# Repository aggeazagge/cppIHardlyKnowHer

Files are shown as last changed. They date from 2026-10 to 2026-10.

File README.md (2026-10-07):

# Autonomonomous car by C++, I hardly know her

A school project building autonomous vehicles that drive themselves along a
walled track about 1 m wide. The firmware is written in MicroPython for an
ESP32-family board. Each vehicle uses three time-of-flight distance sensors to
stay centered between the walls, a Pololu Motoron motor controller, and a start
module that tells it when to go.

### Code

| Folder | Vehicle | Description |
|---|---|---|
| [snok_1.2](snok_1.2/README.md) | RC car | Ackermann steering with a servo and one drive motor. Detects when it is stuck and reverses out |
| [huggorm_1.0](huggorm_1.0/README.md) | Tracked chassis | Excavator with two tracks, steers by the speed difference between them |

Each folder is a complete firmware. To run one, copy its `config.py`, `main.py`
and `lib/` to the board, for example with Thonny. All tunable values are in `config.py`.

### Components

- VL53L4CX ToF lidar sensor – left and right side sensors
- VL53L0X ToF lidar sensor – front (middle) sensor
- Pololu Motoron M2T550 dual I2C motor controller
- DC-DC step-down converter (1.23–30 V, 1.5 A)
- Slide switch (on-on)
- GT Power B3 battery charger

### PCB-schematics

[Kicad/Bil v 1,0](Kicad/Bil%20v%201,0) contains the KiCad project for the
car's circuit board: the schematic, the PCB layout, and the custom symbol
libraries (`Auto_car_library`, `motron_i2c_3motor`).

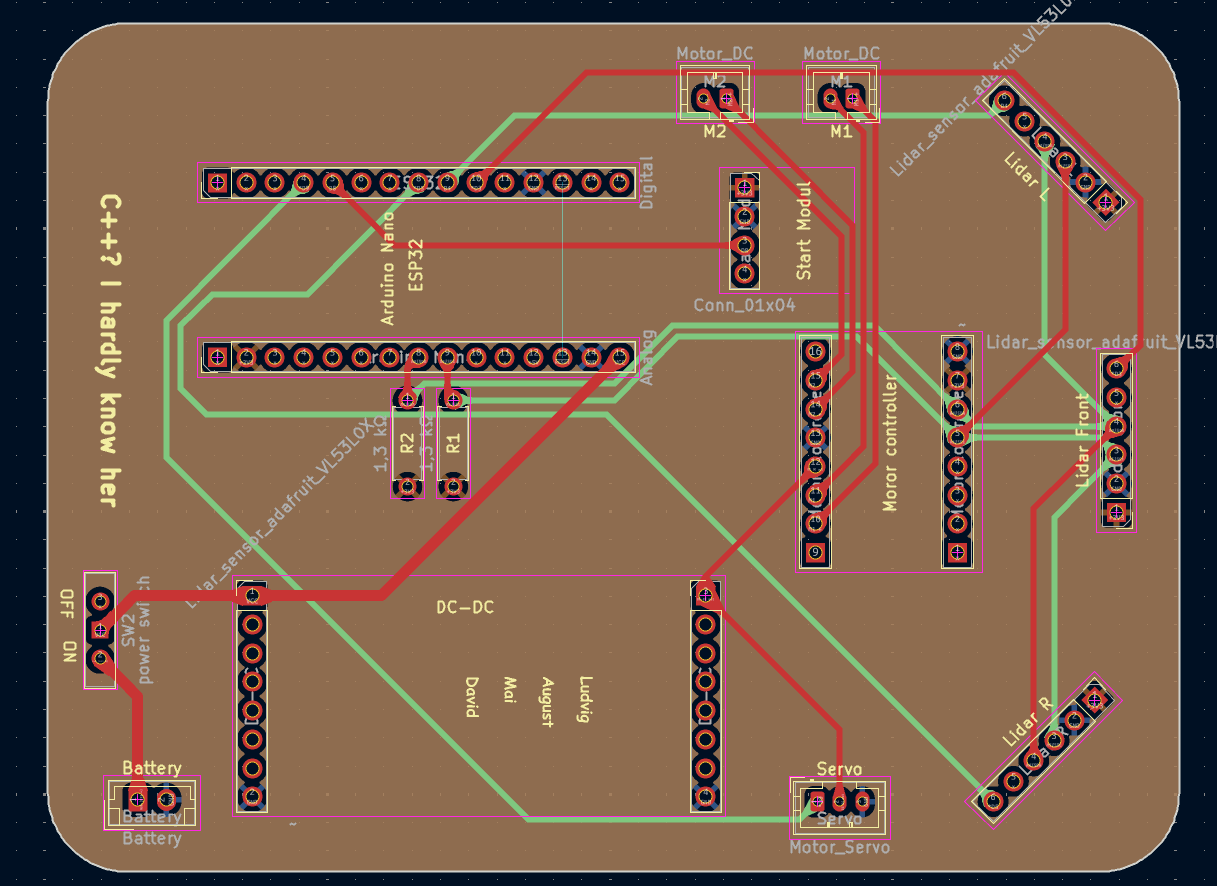
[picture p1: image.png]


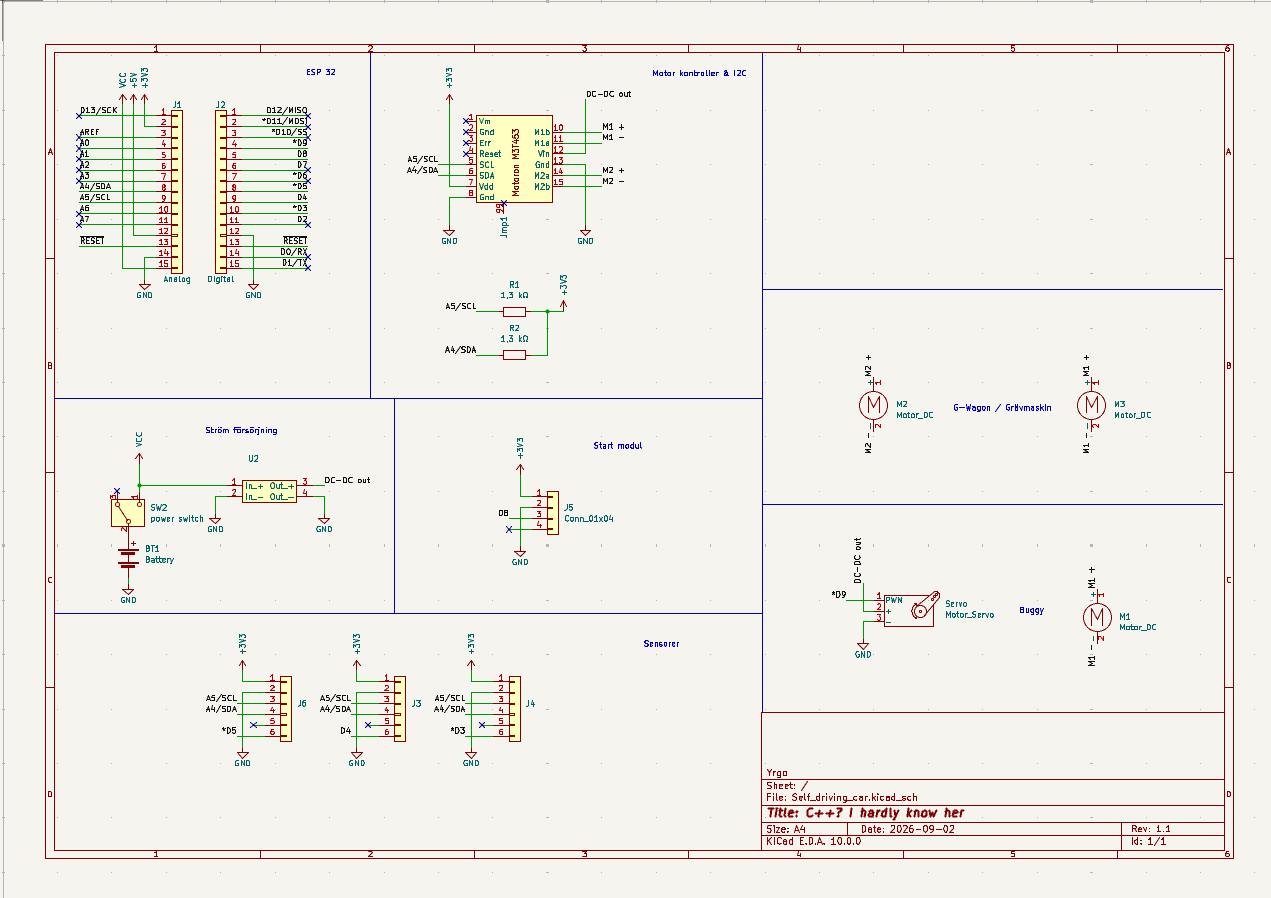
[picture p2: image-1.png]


### License

See [LICENSE](LICENSE).

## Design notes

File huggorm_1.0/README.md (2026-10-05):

# Huggorm 1.0 – autonomous tracked chassis firmware

MicroPython firmware for a tracked, skid-steer chassis with two independent
tracks and no steering servo. It drives itself down a walled track about 1 m
wide, using three time-of-flight sensors to stay centered: VL53L4CX sensors on
the left and right, angled outward, and a VL53L0X in the middle. Both tracks run
at `CRUISE_SPEED`, and the chassis steers by slowing the inside track. There is
no reverse.

## Hardware / wiring

ESP32-family MicroPython board. The pin numbers come from `config.py` and
`lib/lidar_sensor.py`.

| Signal | Pin | Notes |
|---|---|---|
| I2C SDA / SCL | GPIO11 / GPIO12 | shared bus for the sensors and the Motoron, 400 kHz |
| Left ToF (VL53L4CX) XSHUT | GPIO8 | reassigned to `0x30` |
| Middle ToF (VL53L0X) XSHUT | GPIO6 | default `0x29` |
| Right ToF (VL53L4CX) XSHUT | GPIO7 | reassigned to `0x31` |
| Start module | GPIO17 | level and pull set in `config.py` |

The Motoron is at `0x10` and drives the left track on channel 1 and the right
track on channel 2.

All three sensors power up at address `0x29`. To fix that, `lidar_sensor.py`
holds them in reset with XSHUT and then releases them one at a time, giving each
its own address. This has to happen before the Motoron is set up, because
`main.py` reuses the same I2C bus.

## How it runs

`boot.py` is the stock stub. `main.py` sets up the Motoron and calls `run()`,
an infinite loop that only drives while the start pin is active. While the pin
is inactive, it brakes both tracks.

To deploy, copy `boot.py`, `config.py`, `main.py` and `lib/` to the board and
power-cycle it.

## Control loop

Every ~10 ms (`LOOP_DELAY_MS`): read sensors → `compute(dl, dr)` → set track
speeds.

- **Steering fraction:** `dr - dl` is clamped to `±STEER_SPAN_MM` and turned
  into a fraction from -1 (full left) to +1 (full right).
- **Differential speed:** only the inside track slows down:
  `left = CRUISE_SPEED * (1 - TURN_SLOWDOWN * max(0, -frac))`, and the same for
  `right` with `max(0, frac)`. The outside track always runs at full speed.
- The middle sensor is read and logged but not used for control.
- There is no reverse. A pivot turn would be possible on this chassis and could
  be added if `TURN_SLOWDOWN` isn't enough for sharp corners.

## Sensors and safety

- Readings of `0` or `>= DIST_MAX` count as "open", invalid range statuses
  are ignored, and a rolling median (`SENSOR_AVG_SAMPLES`, keep it odd) removes
  spikes.
- The sensors run in continuous mode (about 33 ms timing budget), so reading
  them is quick. A read that times out keeps the last value. A sensor is
  restarted after `SENSOR_RESTART_AFTER_FAILS` failures and declared dead after
  `SENSOR_MAX_FAILS`, which brakes the chassis.
- The Motoron command timeout is left on, so the tracks stop within about
  1.5 s if the loop hangs.
- If the start signal drops or the loop throws, `stop_all()` brakes both
  tracks.

## Tuning

Every bench-tunable constant is in `config.py` with a comment.

## File map

| File | Role |
|---|---|
| `boot.py` | MicroPython boot hook (unmodified stub) |
| `config.py` | All pins and tunable constants |
| `main.py` | Hardware setup, `compute()` and the `run()` loop |
| `lib/lidar_sensor.py` | I2C bus, sensor bring-up and smoothed `las_avstand()` |
| `lib/motoron.py`, `lib/motoron_protocol.py` | Pololu Motoron driver (vendored) |
| `lib/vl53l0x.py`, `lib/vl53l4cx.py` | ToF sensor drivers (vendored) |

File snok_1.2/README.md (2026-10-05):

# Snok 1.2 – autonomous RC car firmware

MicroPython firmware for an Ackermann-steered RC car (one drive motor and a
steering servo) that drives itself down a walled track about 1 m wide. It uses
three time-of-flight sensors to stay centered: VL53L4CX sensors on the left and
right, angled outward, and a VL53L0X in the middle. New in 1.2: the car notices
when it is stuck against an obstacle and reverses out.

## Hardware / wiring

ESP32-family MicroPython board. The pin numbers come from `config.py` and
`lib/lidar_sensor.py`.

| Signal | Pin | Notes |
|---|---|---|
| I2C SDA / SCL | GPIO11 / GPIO12 | shared bus for the sensors and the Motoron, 400 kHz |
| Left ToF (VL53L4CX) XSHUT | GPIO7 | reassigned to `0x30` |
| Middle ToF (VL53L0X) XSHUT | GPIO6 | default `0x29` |
| Right ToF (VL53L4CX) XSHUT | GPIO8 | reassigned to `0x31` |
| Steering servo | GPIO18 | 50 Hz, 544–2400 µs |
| Start module | GPIO17 | level and pull set in `config.py` |

The Motoron motor controller is at I2C address `0x10` and drives the motor on
channel 1. `MOTOR_INVERT = True` because the motor wires are swapped.

All three sensors power up at address `0x29`. To fix that, `lidar_sensor.py`
holds them in reset with XSHUT and then releases them one at a time, giving each
its own address. This runs when the module is imported, before the Motoron is
set up.

## How it runs

`main.py` is the entry point and calls `run()` at the bottom. `run()` is an
infinite loop that only drives while the start pin is active. While the pin is
inactive, it brakes and centers the wheels with `stop_all()`.

To deploy, copy `config.py`, `main.py` and `lib/` to the board (for example with
mpremote or Thonny) and power-cycle it.

## Control loop

Each iteration (`LOOP_DELAY_MS`) does: read sensors → compute steering and
speed → apply → repeat.

- **Steering:** `dr - dl` is clamped to `±STEER_SPAN_MM` and turned into a
  fraction from -1 (full left) to +1 (full right), which is then mapped to a
  servo angle around `STEER_CENTER_DEG`. The side sensors keep the car centered
  between the walls. They are not used as obstacle sensors.
- **Corners:** when the middle sensor reads below `DIST_SLOW`, the steering
  fraction is multiplied by `CORNER_STEER_GAIN` so the car commits harder to the
  turn, and speed drops by `TURN_SLOWDOWN`.
- **Speed:** speed depends only on the middle sensor. The car drives at
  `CRUISE_SPEED` at `DIST_CLEAR` or more, ramps down toward `DIST_STOP`, and
  never goes below `TURN_CRAWL_SPEED`.
- **Stuck detection (new):** `check_stuck()` reports the car as stuck when an
  obstacle is less than 250 mm ahead and the distance has changed by less than
  15 mm for 2 s. `backWard()` then reverses at `BACK_SPEED` for 1 s with the
  wheels straight.
- **Hill blackout:** if all three sensors read `DIST_MAX` for
  `BLACKOUT_CONFIRM_FRAMES` frames in a row, the car is probably pitched up on a
  hill and looking over the walls. It then holds half of the last steering
  angle and drives at `HILL_BLIND_SPEED`.

## Sensors and safety

- Readings of `0` or `>= DIST_MAX` count as "open", invalid range statuses
  are ignored, and a rolling median (`SENSOR_AVG_SAMPLES`) removes spikes.
- The sensors run in continuous mode, so reading them is quick. A read that
  times out keeps the last value. A sensor is restarted after
  `SENSOR_RESTART_AFTER_FAILS` failures and declared dead after
  `SENSOR_MAX_FAILS`, which brakes the car.
- The Motoron command timeout is left on, so the motor stops within about
  1.5 s if the loop hangs.
- Any exception in `run()` calls `stop_all()` before re-raising it.

More detail on the sensor stack is in [huggorm_1.0/README.md](../huggorm_1.0/README.md).

## Tuning

Every bench-tunable constant is in `config.py` with a comment: speeds,
distance thresholds, steering angles and gains, and sensor timing. Calibrate
`STEER_CENTER_DEG`, `STEER_LEFT_DEG` and `STEER_RIGHT_DEG` on the bench.

## File map

| File | Role |
|---|---|
| `config.py` | All pins and tunable constants |
| `main.py` | Hardware setup, `compute()`, stuck detection and reverse, the `run()` loop |
| `lib/lidar_sensor.py` | I2C bus, sensor bring-up and smoothed `las_avstand()` |
| `lib/servo.py` | Steering servo driver |
| `lib/motoron.py`, `lib/motoron_protocol.py` | Pololu Motoron driver (vendored) |
| `lib/vl53l0x.py`, `lib/vl53l4cx.py` | ToF sensor drivers (vendored) |

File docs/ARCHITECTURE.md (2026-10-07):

# Snok 1.2 Architecture

How the autonomous car's code is wired: three distance sensors feed a control law that drives the steering servo and the Motoron motor controller. Blue is the normal driving path; orange marks the safety paths (stop, blackout, reverse).

To view the full page, open [architecture.html](architecture.html) in a browser.

## System block diagram

System block diagram: sensors and start module feed lidar_sensor.py and main.py, which drive the steering servo and the Motoron motor controller

All three sensors and the Motoron share one I²C bus, created in `lib/lidar_sensor.py` and reused by `main.py`. A sensor that misses 3 reads in a row gets its continuous mode restarted; after 10 it raises, and `run()` catches the error and calls `stop_all()`. The Motoron's own command timeout also stops the motor if the loop stalls.

## Main loop

Flowchart of run() in main.py

One pass of `run()` in `main.py`. Any exception, including a dead sensor or Ctrl-C, leaves the loop through `stop_all()`. The blackout branch exists because the car pitches nose-up on a hill and all three beams can look over the walls.

| Setting (`Config.py`) | Value | Effect |
|---|---|---|
| `DIST_CLEAR` | 1000 mm | middle sensor at or above this → full cruise |
| `DIST_SLOW` | 750 mm | below this → slow down, steering ×3.5 |
| `DIST_STOP` | 300 mm | at or below this → crawl speed |
| `CRUISE_SPEED` | 250 | normal forward speed (Motoron units, max 800) |
| `STEER_LEFT/CENTER/RIGHT_DEG` | 60° / 90° / 120° | steering servo angles |
| `STEER_SPAN_MM` | 500 mm | `dr − dl` difference that gives full steering lock |

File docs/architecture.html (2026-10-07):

snok1.2 · MicroPython

# Snok 1.2 Architecture

How the autonomous car's code is wired: three distance sensors feed a control law that drives the steering servo and the Motoron motor controller. Blue is the normal driving path; orange marks the safety paths (stop, blackout, reverse).

## System block diagram

All three sensors and the Motoron share one I²C bus, created in lidar_sensor.py and reused by main.py. A sensor that misses 3 reads in a row gets its continuous mode restarted; after 10 it raises, and run() catches the error and calls stop_all(). The Motoron's own command timeout also stops the motor if the loop stalls.

## Main loop

One pass of run() in main.py. Any exception, including a dead sensor or Ctrl-C, leaves the loop through stop_all(). The blackout branch exists because the car pitches nose-up on a hill and all three beams can look over the walls.

DIST_CLEAR 1000 mm → cruise DIST_SLOW 750 mm → slow, steer ×3.5 DIST_STOP 300 mm → crawl CRUISE_SPEED 250 STEER 60° · 90° · 120° STEER_SPAN 500 mm = full lock

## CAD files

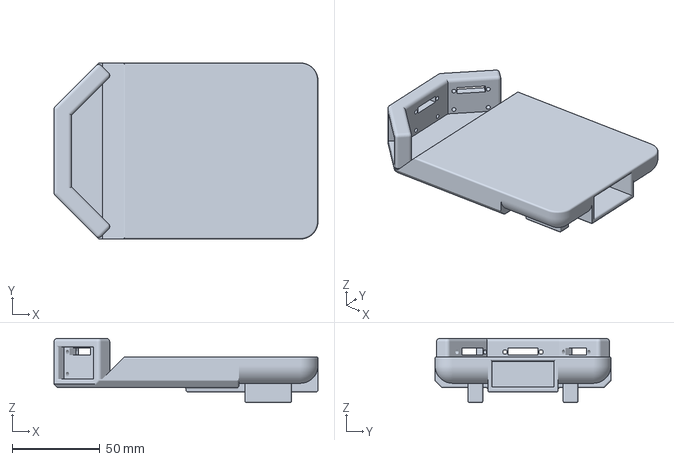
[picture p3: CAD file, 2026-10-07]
Hardware/3D models/excavator 1_0 straight sensors.3mf
150.0 x 100.0 x 36.5 mm

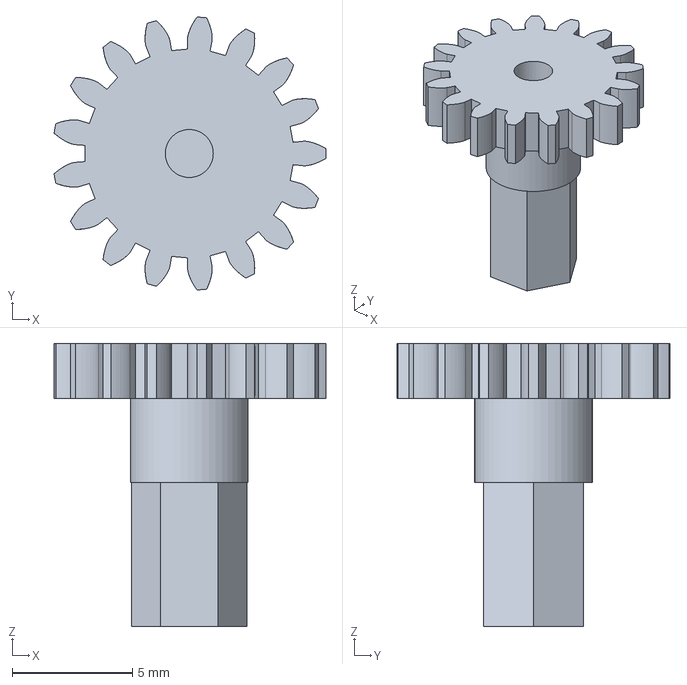
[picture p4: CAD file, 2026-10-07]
Hardware/3D models/gear 1_4 test.FCStd
11.3 x 11.4 x 11.8 mm

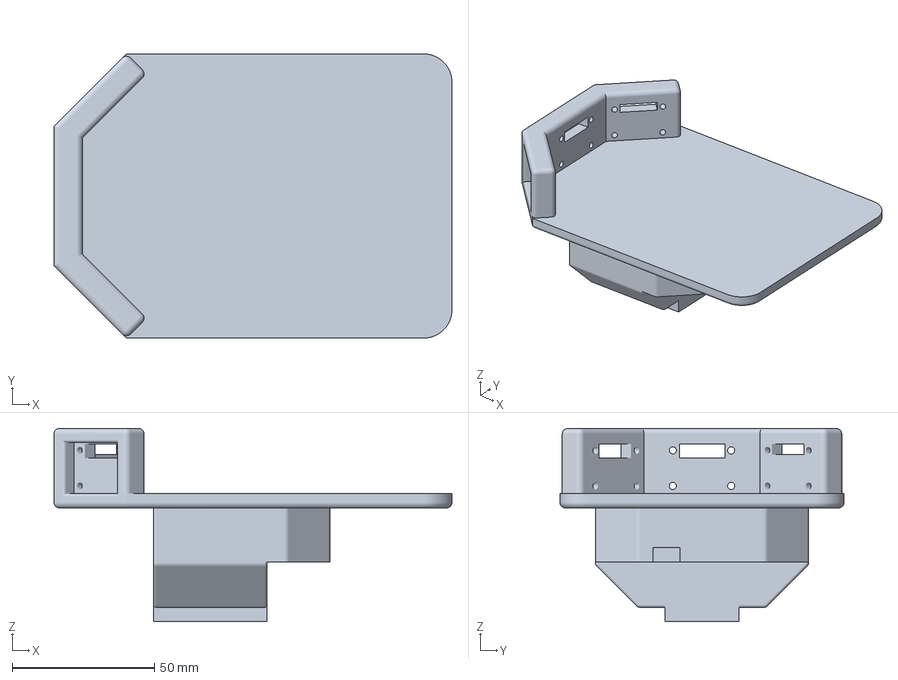
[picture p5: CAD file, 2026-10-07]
Hardware/3D models/body car v1_4 straight sensors final-BodyFillet011.3mf
140.0 x 100.0 x 68.0 mm

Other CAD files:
Hardware/3D models/gear 1_4 test-BodyPocket001.3mf

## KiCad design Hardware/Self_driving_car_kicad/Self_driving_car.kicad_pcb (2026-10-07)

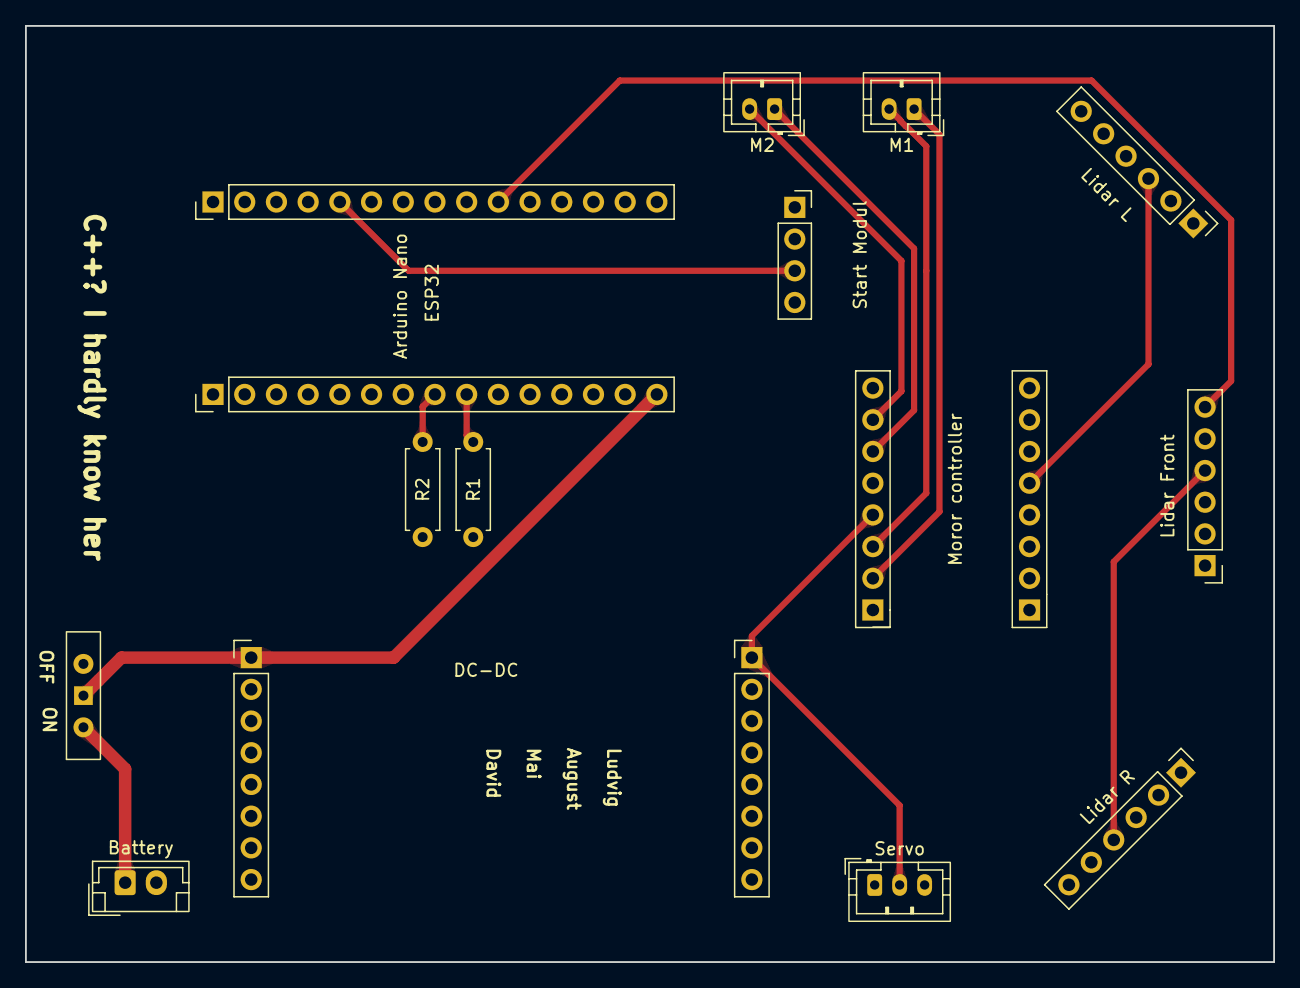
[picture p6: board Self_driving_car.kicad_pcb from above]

Board: 4 copper layers, 100.0 x 75.0 mm, 15 parts (0 on the bottom side), 17 nets.

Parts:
Arduino Nano: Analog; PinHeader_1x15_P2.54mm_Vertical
Battery: Battery; JST_EH_B2B-EH-A_1x02_P2.50mm_Vertical
DC-DC: DC_DC
ESP32: Digital; PinHeader_1x15_P2.54mm_Vertical
Lidar Front: Lidar_sensor_adafruit_VL53L0X; PinHeader_1x06_P2.54mm_Vertical
Lidar L: Lidar_sensor_adafruit_VL53L0X; PinHeader_1x06_P2.54mm_Vertical
Lidar R: Lidar_sensor_adafruit_VL53L0X; PinHeader_1x06_P2.54mm_Vertical
M1, M2: Motor_DC; JST_PH_B2B-PH-K_1x02_P2.00mm_Vertical
Moror controller: Motron motorcontroller 2 motor
R1, R2: 1,3 kΩ; R_Axial_DIN0207_L6.3mm_D2.5mm_P7.62mm_Horizontal
SW2: power switch; SW_Slide-03_Wuerth-WS-SLTV_10x2.5x6.4_P2.54mm
Servo: Motor_Servo; JST_PH_B3B-PH-K_1x03_P2.00mm_Vertical
Start Modul: Conn_01x04; PinSocket_1x04_P2.54mm_Vertical

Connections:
+3V3: Arduino Nano.2, Lidar Front.1 (Vin), Lidar L.1 (Vin), Lidar R.1 (Vin), Moror controller.7 (Vdd), R1.2, R2.2, Start Modul.1
/*D3: ESP32.10, Lidar Front.6 (Xshut)
/*D5: ESP32.8, Lidar R.6 (Xshut)
/*D9: ESP32.4, Servo.1 (PWM)
/A4/SDA: Arduino Nano.8, Lidar Front.4 (SDA), Lidar L.4 (SDA), Lidar R.4 (SDA), Moror controller.6 (SDA), R2.1
/A5/SCL: Arduino Nano.9, Lidar Front.3 (SCL), Lidar L.3 (SCL), Lidar R.3 (SCL), Moror controller.5 (SCL), R1.1
/D4: ESP32.9, Lidar L.6 (Xshut)
/D8: ESP32.5, Start Modul.3
/DC-DC out: DC-DC.3 (Out_+), Moror controller.12 (Vin), Servo.2 (+)
/M1 +: M1.1 (+), Moror controller.10 (M1b)
/M1 -: M1.2 (-), Moror controller.11 (M1a)
/M2 +: M2.1 (+), Moror controller.14 (M2a)
/M2 -: M2.2 (-), Moror controller.15 (M2b)
/~RESET: Arduino Nano.13, ESP32.13
GND: Arduino Nano.14, Battery.2 (-), DC-DC.2 (in_-), DC-DC.4 (Out_-), ESP32.12, Lidar Front.2 (GND), Lidar L.2 (GND), Lidar R.2 (GND), Moror controller.8 (Gnd), Moror controller.13 (Gnd), Servo.3 (-), Start Modul.2
unnamed: Battery.1 (+), SW2.2 (B)
VCC: Arduino Nano.15, DC-DC.1 (in_+), SW2.1 (C)

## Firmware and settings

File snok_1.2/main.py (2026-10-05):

# Autonomous driving loop.
#
# MicroPython runs boot.py then main.py on power-up, so this file is the entry
# point. It wires together the three libraries in this project:
#   - lidar_sensor : three distance sensors (VL53L4CX left/right, VL53L0X middle)
#   - motoron      : Pololu Motoron controller for the drive motor
#   - servo        : the steering servo
# and runs a reactive obstacle-avoidance loop: steer toward open space and slow
# down as obstacles get closer. There is no reverse -- dead ends are handled by
# committing harder to the turn (see compute()) rather than backing out.

import time
from machine import Pin

import config
import lidar_sensor          # importing this brings up the I2C bus + 3 sensors
import motoron
from servo import Servo


# --- Hardware setup ---------------------------------------------------------

# Reuse the I2C bus that lidar_sensor already created on the GPIO11/12 pins;
# the Motoron (0x10) does not collide with the VL53L0X addresses.
mc = motoron.MotoronI2C(bus=lidar_sensor.i2c, address=config.MOTORON_ADDRESS)
mc.reinitialize()
mc.clear_reset_flag()
mc.set_max_acceleration(config.MOTOR_CHANNEL, config.MOTOR_MAX_ACCEL)
mc.set_max_deceleration(config.MOTOR_CHANNEL, config.MOTOR_MAX_DECEL)
# The Motoron command timeout stays enabled on purpose: if this loop ever
# stalls, the motor stops on its own within ~1.5 s.

steering = Servo(
    config.SERVO_PIN,
    min_us=config.SERVO_MIN_US,
    max_us=config.SERVO_MAX_US,
    min_deg=config.SERVO_MIN_DEG,
    max_deg=config.SERVO_MAX_DEG,
    freq=config.SERVO_FREQ_HZ,
)

_PULL = {"up": Pin.PULL_UP, "down": Pin.PULL_DOWN, None: None}[config.START_PIN_PULL]
start_pin = Pin(config.START_MODULE, Pin.IN, _PULL)


# --- Helpers ---------------------------------------------------------------

def clamp(value, low, high):
    return low if value < low else high if value > high else value


def start_requested():
    """True when the start module says 'go'."""
    active_level = 0 if config.START_ACTIVE_LOW else 1
    return start_pin.value() == active_level


def set_steer(angle_deg):
    lo = min(config.STEER_LEFT_DEG, config.STEER_RIGHT_DEG)
    hi = max(config.STEER_LEFT_DEG, config.STEER_RIGHT_DEG)
    steering.write(clamp(angle_deg, lo, hi))


def drive(speed):
    speed = int(clamp(speed, -config.MOTOR_MAX_SPEED, config.MOTOR_MAX_SPEED))
    if config.MOTOR_INVERT:
        speed = -speed
    mc.set_speed(config.MOTOR_CHANNEL, speed)


def stop_all():
    """Brake hard and re-center the wheels. Safe to call any time."""
    mc.set_braking_now(config.MOTOR_CHANNEL, config.MOTOR_BRAKE_AMOUNT)
    set_steer(config.STEER_CENTER_DEG)


# --- Control law ---------------------------------------------------------

def compute(dl, dm, dr):
    """Map (left, middle, right) distances in mm to (steer_deg, speed).

    The sensors are splayed (left looks forward-left, right forward-right), so on
    a ~1 m track the side readings are a wall-centering signal, not obstacles:
    steer to keep dl ~= dr. Speed comes from the middle sensor alone.
    """
    # Steer to re-center between the walls. frac: -1 = hard left, +1 = hard right.
    diff = clamp(dr - dl, -config.STEER_SPAN_MM, config.STEER_SPAN_MM)
    frac = diff / config.STEER_SPAN_MM

    # Wall dead ahead (sharp corner) -> commit harder to the turn.
    if dm < config.DIST_SLOW:
        frac = clamp(frac * config.CORNER_STEER_GAIN, -1.0, 1.0)

    half = min(
        config.STEER_CENTER_DEG - config.STEER_LEFT_DEG,
        config.STEER_RIGHT_DEG - config.STEER_CENTER_DEG,
    )
    steer_deg = config.STEER_CENTER_DEG + frac * half

    # Speed from forward clearance (middle sensor) only.
    if dm >= config.DIST_CLEAR:
        speed = config.CRUISE_SPEED
    elif dm <= config.DIST_STOP:
        speed = config.TURN_CRAWL_SPEED      # nose near a wall, still turning
    else:
        span = config.DIST_CLEAR - config.DIST_STOP
        t = (dm - config.DIST_STOP) / span
        speed = config.CRUISE_SPEED * (0.4 + 0.6 * t)

    # Ease off for hard steering, but only when there's a wall coming up ahead
    # (dm < DIST_SLOW). With a clear corridor a big steering input is just
    # wall-centering / a gentle bend and shouldn't cost speed.
    if dm < config.DIST_SLOW:
        speed *= (1.0 - config.TURN_SLOWDOWN * abs(frac))
    speed = max(speed, config.TURN_CRAWL_SPEED)

    return steer_deg, speed
def backWard():
    print("BACKAR!")

    # Håll hjulen raka
    set_steer(config.STEER_CENTER_DEG)

    # Backa
    drive(config.BACK_SPEED)
    time.sleep_ms(1000)

    # Stoppa
    stop_all()

    # Nollställ fastkörningshistoriken
    global stuck_start, last_middle_distance

    stuck_start = None
    last_middle_distance = None




STUCK_DISTANCE = 250       # mm - hinder närmare än 25 cm
STUCK_TIME_MS = 2000       # 2 sekunder
STUCK_CHANGE_MM = 15        # max förändring i avstånd


stuck_start = None
last_middle_distance = None


STUCK_DISTANCE = 250       # mm
STUCK_TIME_MS = 2000       # 2 sekunder
STUCK_CHANGE_MM = 15       # max förändring

stuck_start = None
last_distances = None

def check_stuck(dl, dm, dr, speed):
    global stuck_start, last_middle_distance

    # Om bilen inte kör framåt -> återställ
    if speed <= 0:
        stuck_start = None
        last_middle_distance = None
        return False

    now = time.ticks_ms()

    # Vi bryr oss bara om ett hinder nära framför bilen
    if dm > STUCK_DISTANCE:
        stuck_start = None
        last_middle_distance = dm
        return False

    # Första mätningen
    if last_middle_distance is None:
        last_middle_distance = dm
        stuck_start = now
        return False

    # Har avståndet ändrats tillräckligt?
    change = abs(dm - last_middle_distance)

    if change > STUCK_CHANGE_MM:
        # Bilen rör sig -> inte fast
        stuck_start = None
        last_middle_distance = dm
        return False

    # Avståndet ändras nästan inte
    if stuck_start is None:
        stuck_start = now

    elapsed = time.ticks_diff(now, stuck_start)

    if elapsed >= STUCK_TIME_MS:
        print("FASTNAT FRAMFÖR! Avstånd:", dm)
        stuck_start = None
        last_middle_distance = dm
        return True

    last_middle_distance = dm
    return False


# mätte spänningen på data pinnen sda
# --- Main loop ---------------------------------------------------------

def run():
    print("autonomous loop ready -- waiting for start signal")
    was_running = False
    last_steer_deg = config.STEER_CENTER_DEG
    blackout_streak = 0
    try:
        while True:
            if not start_requested():
                if was_running:
                    print("start signal off -- stopping")
                stop_all()
                was_running = False
                last_steer_deg = config.STEER_CENTER_DEG
                blackout_streak = 0
                time.sleep_ms(config.LOOP_DELAY_MS)
                continue

            if not was_running:
                print("start signal on -- driving")
                was_running = True

            dl, dm, dr = lidar_sensor.las_avstand()

            # All three sensors maxed for several frames in a row -> almost
            # certainly a hill blind spot (beams pointing over the walls),
            # not a genuinely open track. Hold the last heading and crawl
            # instead of trusting "open" and cruising at full speed.
            if dl >= config.DIST_MAX and dm >= config.DIST_MAX and dr >= config.DIST_MAX:
                blackout_streak += 1
            else:
                blackout_streak = 0

            if blackout_streak >= config.BLACKOUT_CONFIRM_FRAMES:
                steer_deg = last_steer_deg/2
                speed = config.HILL_BLIND_SPEED
                blackout_tag = " BLACKOUT"
            else:
                steer_deg, speed = compute(dl, dm, dr)
                if check_stuck(dl, dm, dr, speed):
                    print("Bilen verkar ha fastnat -> backar!")
                    backWard()
                    continue
                last_steer_deg = steer_deg
                blackout_tag = ""

            set_steer(steer_deg)
            drive(speed)
            print(dl, dm, dr, "->", round(steer_deg), int(speed), blackout_tag)

            time.sleep_ms(config.LOOP_DELAY_MS)
    except (KeyboardInterrupt, Exception) as e:
        stop_all()
        print("stopped:", e)
        raise


run()

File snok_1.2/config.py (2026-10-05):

import motoron
from machine import Pin

# Pin definitions
START_MODULE = 17
SERVO_PIN = 18
I2C_SDA_PIN = 11
I2C_SCL_PIN = 12

# Servo settings
SERVO_MIN_DEG = 10.0
SERVO_MAX_DEG = 180.0

# Motor bus setttings
I2C_BUS_ID = 0

# Motor acceleration/deceleration
MOTOR_MAX_ACCEL = 300
MOTOR_MAX_DECEL = 140 # 140 max utan att skickade tillbaka för mycket

# Motor speed (Motoron units, 0..800)
CRUISE_SPEED = 250       # normal forward speed on a clear path
BACK_SPEED = -250
MOTOR_MAX_SPEED = 800

# Braking (Motoron units, 0..800 -- separate scale from speed above: 0 = coast,
# 800 = full brake). Used by stop_all() when the start signal drops.
MOTOR_BRAKE_AMOUNT = 800

# Motoron drive motor
MOTORON_ADDRESS = 16     # 7-bit I2C address (Motoron default)
MOTOR_CHANNEL = 1        # single drive motor on channel 1
MOTOR_INVERT = True      # motor wires are swapped; flip back to False if they're re-wired

# Start module (autonomous-RC start device on START_MODULE / GPIO2)
START_ACTIVE_LOW = False  # car runs when the pin reads this level; flip to run on HIGH
START_PIN_PULL = "down"    # "up" | "down" | None -- internal pull resistor on GPIO2

# Steering angles handed to Servo.write() -- CALIBRATE THESE ON THE BENCH.
# They must sit inside SERVO_MIN_DEG..SERVO_MAX_DEG.
STEER_CENTER_DEG = 90.0  # wheels pointing straight
STEER_LEFT_DEG = 60.0    # full left lock
STEER_RIGHT_DEG = 120.0  # full right lock

# Servo pulse-width limits (microseconds) and update rate for this servo
SERVO_MIN_US = 544.0
SERVO_MAX_US = 2400.0
SERVO_FREQ_HZ = 50

# Obstacle-distance thresholds (mm) -- sized for a ~1 m walled track. Only the
# middle sensor gates speed; the splayed side sensors always see a wall a few
# hundred mm away, so they feed steering only (see compute()).
DIST_MAX = 1200          # readings >= this (or invalid) -> "open"; the VL53L0X
                         # is not trusted past ~1.2 m
DIST_CLEAR = 1000         # middle sensor >= this ahead -> full cruise
DIST_SLOW = 750          # middle sensor < this -> slow down + commit to the turn
DIST_STOP = 300          # middle sensor <= this -> crawl speed, still turning

# Control tuning
STEER_SPAN_MM = 500.0     # (dr - dl) difference that maps to full steering lock
CORNER_STEER_GAIN = 3.5   # extra steering commitment when middle < DIST_SLOW
TURN_SLOWDOWN = 0.6       # speed *= (1 - TURN_SLOWDOWN * |steer fraction|)
LOOP_DELAY_MS = 10        # the blocking sensor reads already pace the loop

# VL53L0X measurement timing budget (microseconds). The driver enforces a
# hard floor of 20000 (see measurement_timing_budget setter in vl53l0x.py);
# using that floor minimizes per-measurement latency at the cost of some
# range/precision headroom this ~1 m track doesn't need. Combined with
# continuous ranging mode (lib/lidar_sensor.py), this is what makes
# las_avstand() fast.
SENSOR_TIMING_BUDGET_US = 20000
# DO NOT lower this or the signal rate limit (driver default 0.25 MCPS)
# without the read timeout below in place: aggressive tuning (e.g. signal
# rate 0.1) made a sensor stop reporting data and the car froze.

# VL53L4CX (left/right sensors) timing budget in milliseconds, 10..200 (see
# set_timing() in lib/vl53l4cx.py). Matches the middle sensor's ~33 ms so all
# three deliver new data at about the same rate.
SIDE_SENSOR_TIMING_BUDGET_MS = 20

# Rolling-median window (samples) for each distance sensor. A single
# spiky/erroneous reading is dropped entirely instead of dragging the value
# the way a mean would. Keep it odd (3 or 5); 1 disables filtering.
SENSOR_AVG_SAMPLES = 3

# Sensor failure handling (see _Channel in lib/lidar_sensor.py). A read that
# gets no new data within SENSOR_READ_TIMEOUT_MS (~3x the timing budget)
# holds the last value instead of hanging. After SENSOR_RESTART_AFTER_FAILS
# consecutive failures the sensor's continuous mode is restarted; after
# SENSOR_MAX_FAILS (~1 s) it's declared dead and the car brakes.
SENSOR_READ_TIMEOUT_MS = 100
SENSOR_RESTART_AFTER_FAILS = 3
SENSOR_MAX_FAILS = 10

# Hill "blackout" handling: on an incline the car pitches nose-up and all
# three sensors can point over the nearby walls, reading DIST_MAX ("open")
# even though a wall is still right there. BLACKOUT_CONFIRM_FRAMES is how
# many consecutive all-maxed loop iterations are required before treating
# it as a blackout (vs. a genuinely open straight or a one-frame fluke).
# HILL_BLIND_SPEED is the speed used while blind -- lower than CRUISE_SPEED
# so less ground (and lateral drift) is covered before sensors regain lock,
# but high enough not to stall climbing the incline. Both bench-tunable.
BLACKOUT_CONFIRM_FRAMES = 5
HILL_BLIND_SPEED = 250

# Forward crawl speed: the minimum forward speed used while turning hard.
# There is no reverse -- this must be low enough, and DIST_SLOW/DIST_STOP/
# CORNER_STEER_GAIN tight enough, that the turn radius actually clears the
# wall. Bench-tune these together if it still clips a corner.
TURN_CRAWL_SPEED = 250

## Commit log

2026-08-20 Project start
    start of schematics
    [Bil v 1,0.kicad_pcb, Bil v 1,0.kicad_sch]
2026-08-21 Buggy car sch 1.0
    Schematic for buggy car, probably correct
    [Bil v 1,0.kicad_sch]
2026-08-21 updated resistor values
    Updated values for I2C resistors so that it (probably) will work with 400 kHz speeds
    [Bil v 1,0.kicad_sch]
2026-08-24 motor layous for the other cars
    added schematics for how motors on the digger and g-wagon should be connected
    [Bil v 1,0.kicad_sch]
2026-08-31 Add sensor
2026-09-03 pcb layouyt1.0
    first draft of pcb layout
    [Bil v 1,0.kicad_pcb, Bil v 1,0.kicad_sch]
2026-09-10 1.3 updated layout
    the probably final board layout, now with power switch
    [Bil v 1,0-B_Cu.gbr, Bil v 1,0-B_Mask.gbr, Bil v 1,0-B_Paste.gbr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]
2026-09-10 Add steering without reverse
    [config.py, main.py]
2026-09-11 1.4 Garber
    Final (probably) version with generated garber files
    [Bil v 1,0-B_Cu.gbr, Bil v 1,0-B_Mask.gbr, Bil v 1,0-B_Paste.gbr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]
2026-09-11 1.4.1 updated silkscreens
    updated silkscreens with names of modules
    [Bil v 1,0-B_Cu.gbr, Bil v 1,0-B_Mask.gbr, Bil v 1,0-B_Paste.gbr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]
2026-09-11 1.4.2 drill files!
    now with 100% more drill files...
    [Bil v 1,0-B_Cu.gbr, Bil v 1,0-B_Mask.gbr, Bil v 1,0-B_Paste.gbr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]
2026-10-01 Renamed project
    Renamed project to self driving car and not car v1.0
    [Bil v 1,0.kicad_pcb, Bil v 1,0.kicad_sch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]
2026-10-07 1.5 new name and models
    renamed kicad project and added 3d models for chassis
    [Self_driving_car-B_Cu.gbr, Self_driving_car-B_Mask.gbr, Self_driving_car-B_Paste.gbr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]
2026-10-07 1.5.1 new name
    name now in english
    [Self_driving_car-B_Cu.gbr, Self_driving_car-B_Mask.gbr, Self_driving_car-B_Paste.gbr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]
